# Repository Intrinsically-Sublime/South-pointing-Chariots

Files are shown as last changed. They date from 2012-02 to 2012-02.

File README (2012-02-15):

---Description---

The south pointing chariot is an ancient mechanical compass invented in China around 200 C.E. Texts mention their use up until around 1300 C.E. and they have descriptions of how they were built. But unfortunately there are no examples of ancient ones still in existence. Thankfully many people over the years have interpreted the ancient texts to come up with a variety of designs. Most of these designs use counter rotating differentials connected to each wheel and a common differential in the center with a pointing device to indicate South. How the differentials are oriented and connected to each other varies greatly though. I found this to be one of the most elegant designs and its attributed to a Mr. Nuttall.

This makes a great Demo showing the capabilities of 3D printing and will impress everyone you show. It only has ONE stationary part and 11-14 moving parts depending on configuration.

Version Information
Spiral gear version is made for printing on a well tuned machine.
It uses GeneralRulOfDumbs' spiral gears at 66% of the original size.
I printed it at 0.14mm layer height with a 0.4mm nozzle at 20mm/s perimeter, 30mm/s infill.

Version Information
Spur gear version is made for printing on the average machine.
It uses 15 tooth spur gears generated by Blender
I printed it at 0.28mm layer height with a 0.4mm nozzle at 20mm/s perimeter, 50mm/s infill.

File organization
All the gears have a small support structure that needs to be removed with a pair of needle nose pliers or screwdriver.

100x100_plate 1&2 are made to fit on 100mm x 100mm build surface.
Plate 1 contains all the parts except the wheels. (one spider gear per side)
Plate 2 contains one wheel. (it needs to be printed twice)

200x200_plate is made to fit on a 200mm x 200mm build surface.
It contains all the parts plus the third and fourth spider gears that are not really required but look cool, plus the tux penguin pictured.

Zip file contains all the parts individually.

The Blend file is very large and processor heavy but 99% parametric (minus the gears).
The spur gear version requires the spiral gear version Blend file for linked parts.

Attribution
Spiral gears by GeneralRulOfDumb thingiverse.com/thing:10955
Gro_tux by Le_Garage thingiverse.com/thing:4745
The math behind it can be seen odts.de/southptr/math/santander.htm
Gear ratio calculator for Nuttall type SPC odts.de/southptr/gears/nuttall.htm

Tools
Needle nose pliers or flat head screw driver. (to remove support)
M6 die (or 1/4" die)
Hex keys (allen keys)
Wrench for M6 nut (or 1/4" nut)
Drill with 4mm and 6mm drill bits (or 11/64" and 1/4")
CA glue (instant glue)

BOM
115mm of 6mm smooth rod (brass is preferred) (I used 1/4" and drilled the holes)
2 * M6 nuts (or 1/4" if using 1/4" smooth rod)
3-5 * M4 x 12 cap screws (I used no8 x 1/2" and drilled the holes)
2 * 5/16 nuts (sorry M8 will not work) threads pitch does not matter
3-10 * M4 or M5 washers. (no8 or no10)
3-5 * M4 nuts (or no8)
2 * 3-15/16" x 3-3/4" x3/32" O-ring (3.9375 x 3.75 x 0.094) (100mm x 95.25mm x 2.4mm)Options / Alternatives

no8 x 1/2" cap screws can be used in place of the M4 x 12 cap screws with a little drilling. (no8 is 0.14mm larger than in diameter than a M4 bolt)

1/4" smooth rod can be used in place of the 6mm smooth rod with a little drilling. (1/4" is 0.3mm larger in diameter than the 6mm smooth rod)

Push on clips can be used in place of the retaining nut on the smooth rod. This eliminates the need for an M6 die (1/4" die). May even be printable.

You can use any mascot you wish. It does require a small recess in the bottom to allow it to sit over the center gears bolt and nut. The recess can easily be added with a drill if you already have something printed.

Only two spider gears are included in the 100x100 plates. If you would like the third and fourth they can be printed from the individual files.

No mascot included in the 100x100 plates. Available in the individual files.

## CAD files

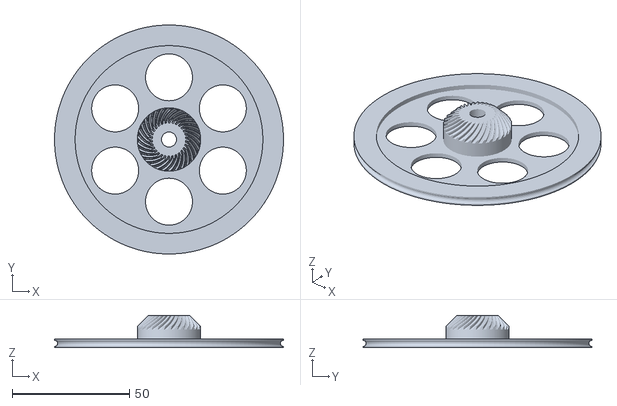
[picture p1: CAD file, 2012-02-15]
South_pointing_chariot_spiral_gear/Finished STL's/100x100_plate_2.stl
97.6 x 97.6 x 13.8

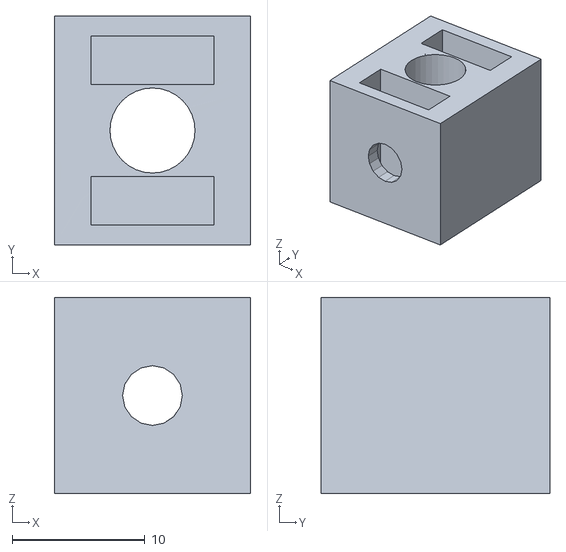
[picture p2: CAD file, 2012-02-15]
South_pointing_chariot_spiral_gear/Finished STL's/Individual_parts/Diff_block.stl
14.8 x 17.2 x 14.8

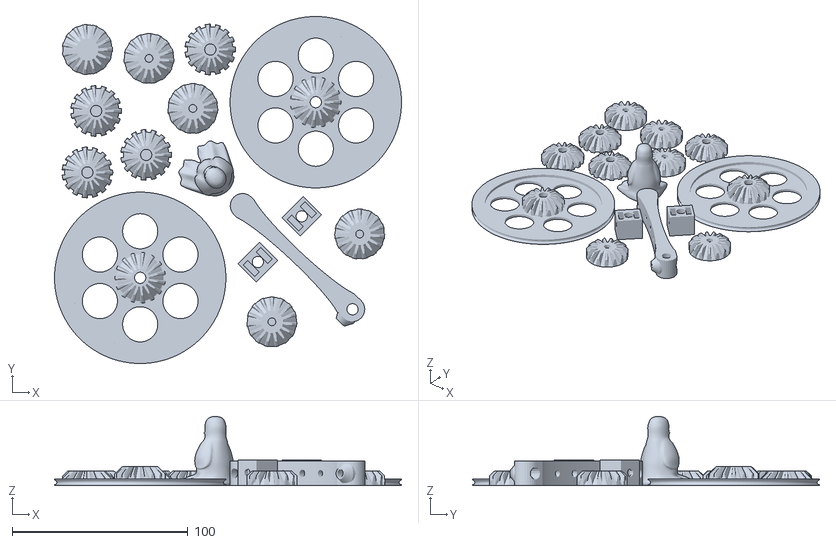
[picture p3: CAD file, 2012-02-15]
South_pointing_chariot_Spur_gear/Finished_stl's/200x200_plate.stl
197.6 x 197.6 x 39.5

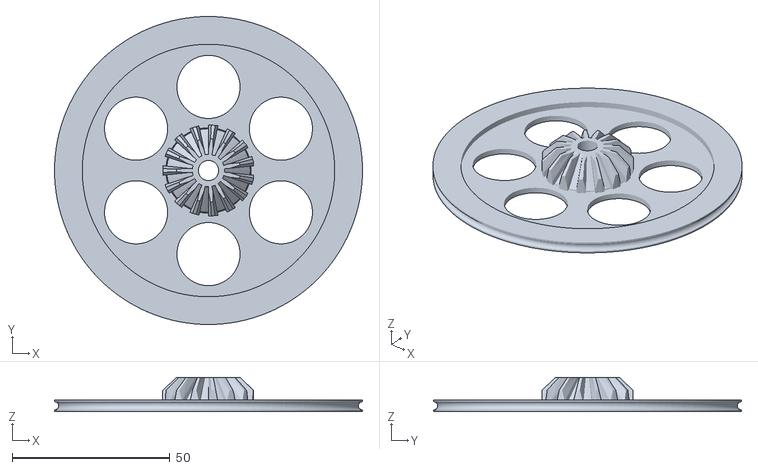
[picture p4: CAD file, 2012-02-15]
South_pointing_chariot_Spur_gear/Finished_stl's/Individual_parts/100x2.4_O-ring_wheel_spur_gear.stl
97.6 x 97.6 x 10.9

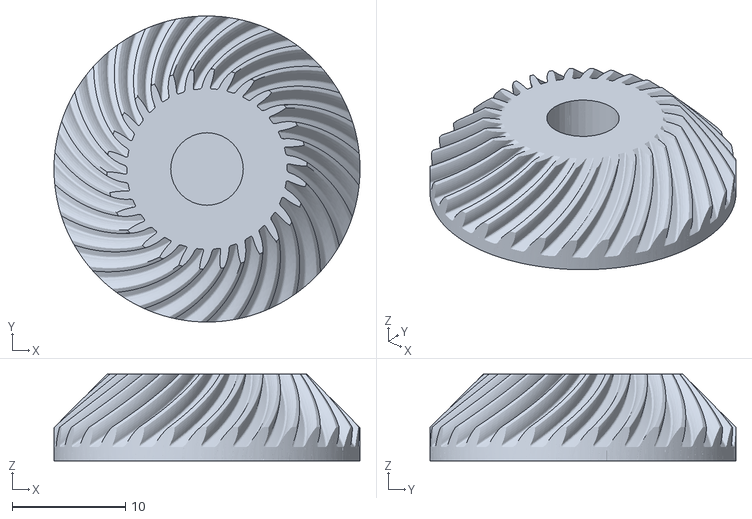
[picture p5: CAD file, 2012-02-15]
South_pointing_chariot_spiral_gear/Finished STL's/Individual_parts/Cluster_gear_A.stl
27.0 x 27.0 x 7.63

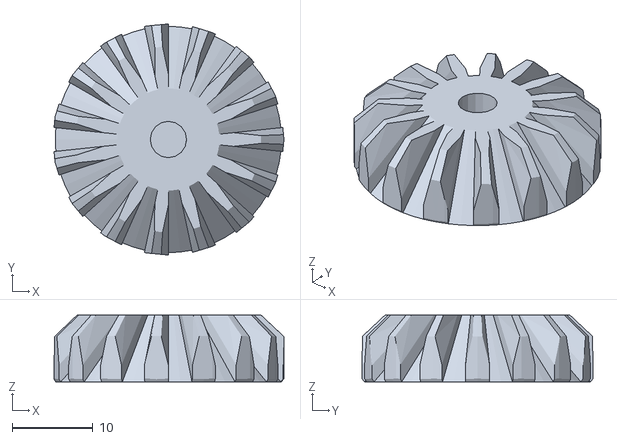
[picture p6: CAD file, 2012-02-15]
South_pointing_chariot_Spur_gear/Finished_stl's/Individual_parts/Center_spur_gear.stl
28.5 x 28.6 x 8.24

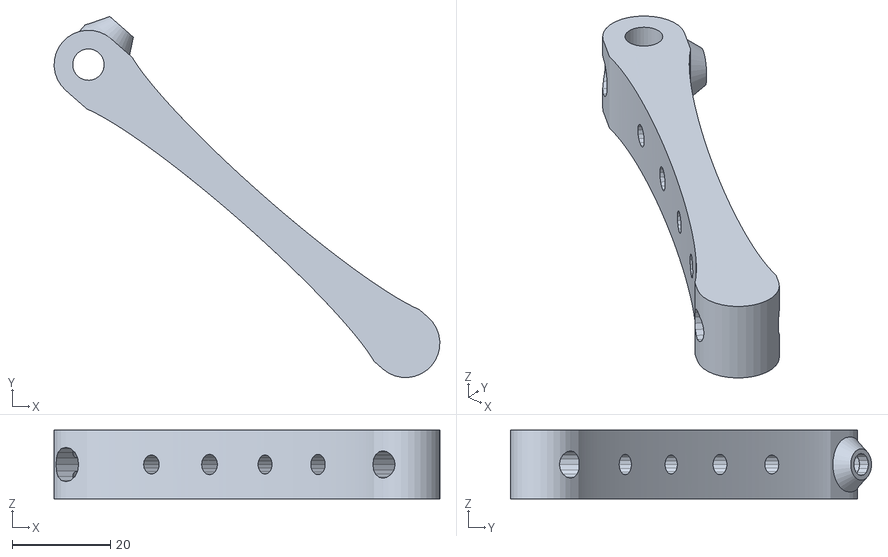
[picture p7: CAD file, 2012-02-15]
South_pointing_chariot_spiral_gear/Finished STL's/Individual_parts/Tongue.stl
78.6 x 73.5 x 14.0

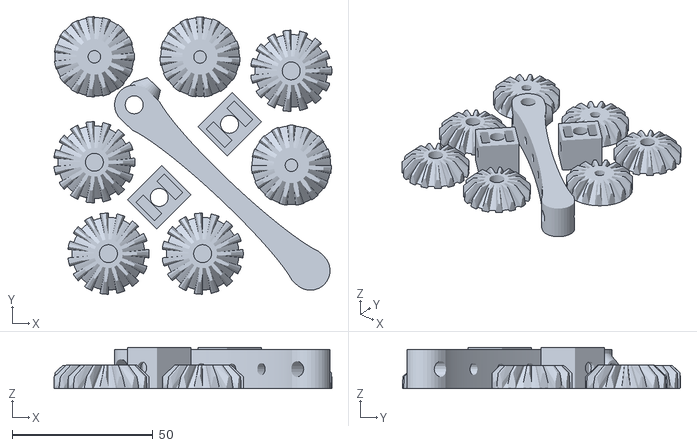
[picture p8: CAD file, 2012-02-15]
South_pointing_chariot_Spur_gear/Finished_stl's/100x100_plate_1.stl
98.8 x 98.8 x 14.8

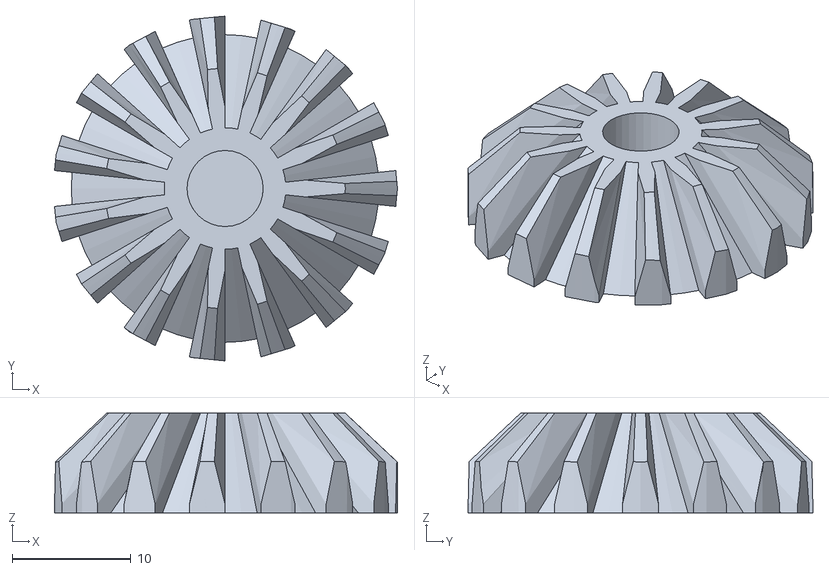
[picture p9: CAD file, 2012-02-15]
South_pointing_chariot_Spur_gear/Finished_stl's/Individual_parts/Cluster_spur_gear.stl
28.9 x 29.0 x 8.39

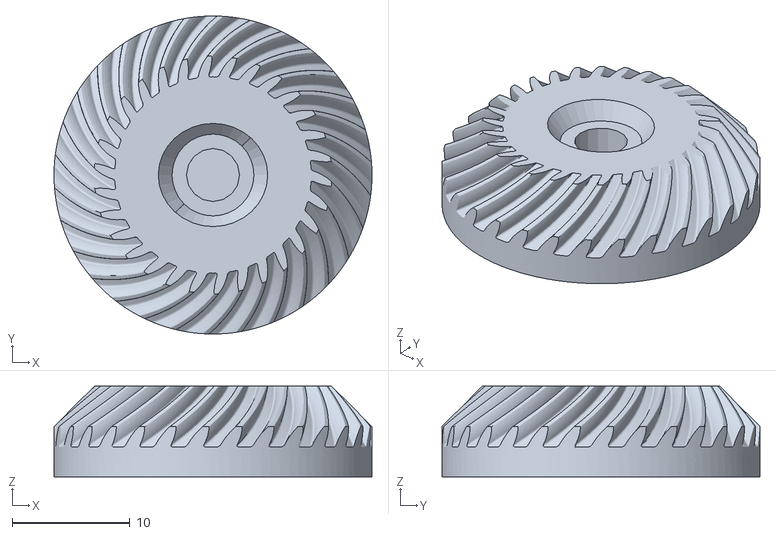
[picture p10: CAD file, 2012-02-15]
South_pointing_chariot_spiral_gear/Finished STL's/Individual_parts/Center_gear.stl
27.0 x 27.0 x 7.68

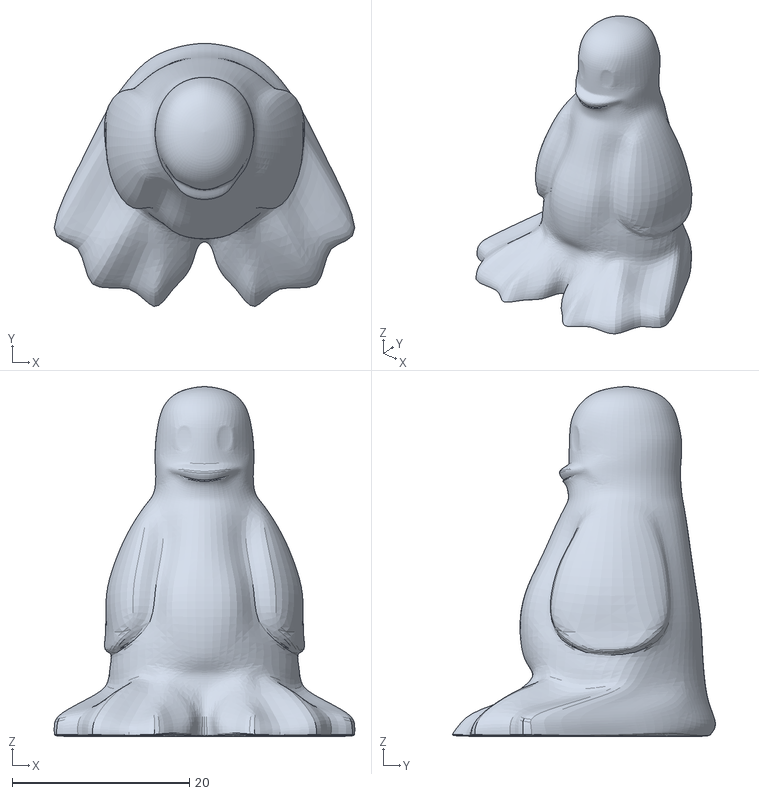
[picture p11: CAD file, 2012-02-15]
South_pointing_chariot_Spur_gear/Finished_stl's/Individual_parts/Gro_tux_hollow.stl
33.9 x 29.7 x 39.5

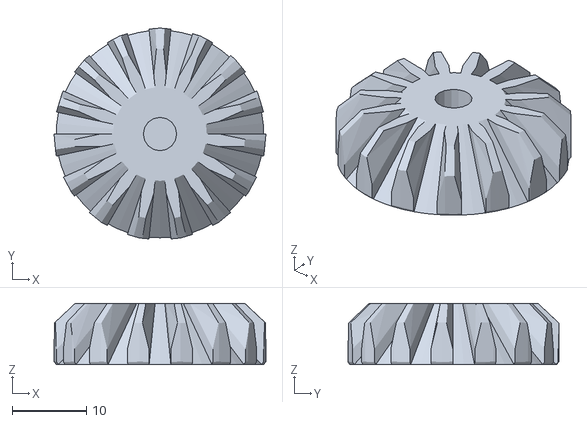
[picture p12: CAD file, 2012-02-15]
South_pointing_chariot_Spur_gear/Finished_stl's/Individual_parts/Spider_spur_gear.stl
28.6 x 28.5 x 8.24

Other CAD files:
South_pointing_chariot_spiral_gear/Finished STL's/Individual_parts/Cluster_gear_B.stl
South_pointing_chariot_spiral_gear/Finished STL's/Individual_parts/Spider_gear.stl
South_pointing_chariot_Spur_gear/Finished_stl's/Individual_parts/Diff_block.stl
South_pointing_chariot_Spur_gear/South_pointing_chariot_Spur_gears.blend
South_pointing_chariot_spiral_gear/Cluster_gear_spiral.blend

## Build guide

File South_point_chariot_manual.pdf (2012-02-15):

Pre-assembly Instructions

1) Remove support from inside gears with a pair of needle nose pliers or flat head screw driver.
2) Clean all parts well.
3) Check M4 bolts turn freely in spider gears, center gear, tongue and differential blocks. Drill if required.
4) Check that the 6mm smooth rod turns freely in tongue, cluster gears, diff blocks and wheels. Drill if required.
5) Install O-rings on wheels. Measure the outer diameter with calipers and write it down (Goal is 100mm).
6) Thread ends of smooth rods with M6 die for 5mm.
7) Press one 5/16" nut in side A of cluster gear (may be loose, DO NOT GLUE) .
8) Press side B of cluster gear over 5/16" nut in side A of cluster gear.

Test Assembly Instructions

1) Install one nut on end of rod.
2) Slide wheel one onto the smooth rod down to the nut with the gear facing away from the nut.
3) Slide one diff block on.
4) Slide one cluster gear on.
5) Slide tongue on.
6) Slide second cluster gear on.
7) Slide second diff block on.
8) Slide second wheel on.
9) Measure from the center of wheel one to the center of wheel two and write it down (wheel track or width from side to side). This width needs to be 2-5mm smaller than the wheel diameter. Ideally if the wheels are 100mm this should measure 98-95mm across.
10) Take it all apart again.

11(a) If it measures within range (2-5mm of wheel diameter) go to final assembly (this is how both of mine were).

11(b) If it measures >5mm smaller than your wheel diameter, you will need to space the cluster gears apart until it's with in range.

11(c) If it measures <2mm smaller than your wheel diameter, you will need to sand the face of the wheel gears, cluster gears, diff blocks and/or tongue.

Final Assembly Instructions

1) Install M4 nuts in diff blocks.
2) Install M4 bolt in tongue for the center gear through the hole in the bottom. Be sure the head is far enough inside that the smooth rod still fits and turns freely. Gluing the bolt head in place with CA glue is recommended but not required.
3) Re-assemble in the same order as previously.
4) Install the second nut.
5) Measure the wheel track again, and set the nuts on either side so that the wheel track is exactly the same as the wheel diameter.
6) Set the space between all the parts on the shaft to have equal spacing. Use folded sheets of paper as spacers to be sure they are all the same.
7) Install one M4 or M5 washer on each remaining bolt.
8) Install bolts with washers in spider gears and screw them to the diff blocks. The bolts should bottom out on the shaft and act as set screws for the diff block. If the gears are too tight move the washers under the gear.
9) Install the center gear with the remaining M4 nut and washer.
10) Check that everything turns freely. If it's tight, try moving some of the washers under the gears or having washers on both sides.
11) If everything moves smoothly and it works as in the video, put a drop of CA glue on the exposed threads on the ends of the smooth rods to prevent the nuts from moving. Also put a small drop on the center gear bolt threads to prevent the nut from coming loose.
12) Glue your favourite mascot or bobble head to the center gear. I have included Le_Garages' Gro_tux with a recess in the bottom for the center gears nut and bolt. I figured it the most appropriate being that they live in the Antarctic circle (South) and he stands for Open Source. It's kind of like he's always looking towards home.
